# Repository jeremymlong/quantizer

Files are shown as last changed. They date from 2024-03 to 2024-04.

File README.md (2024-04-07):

# Dual Quantizer
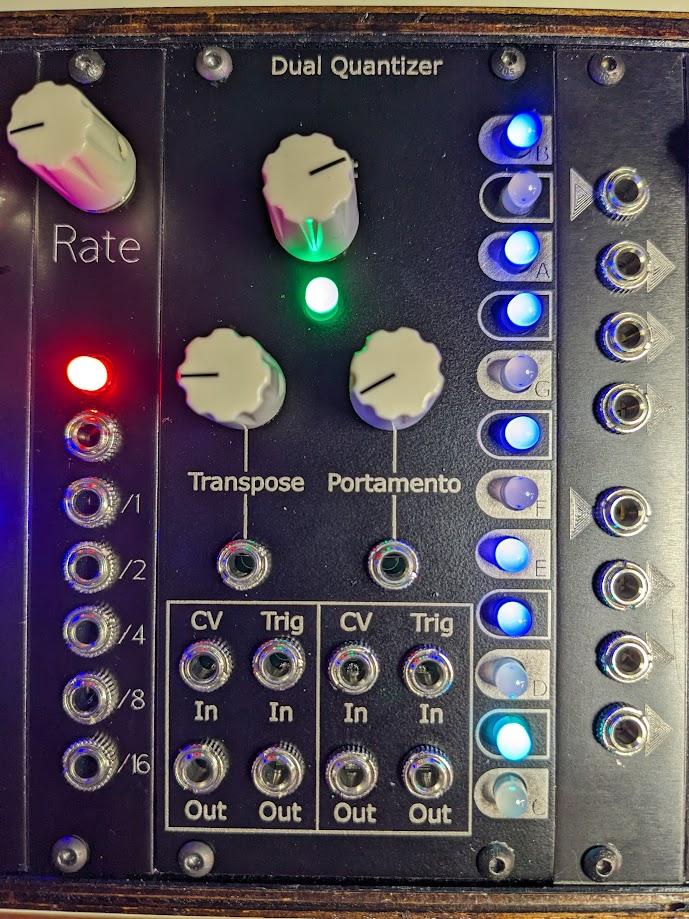
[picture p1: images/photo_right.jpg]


## Specs
 * Range 0 to 5V
 * Arduino Nano based
 * Encoder knob for selecting scale
 * Encoder button for selecting which quantizer is displayed on the LEDs
 * Transpose with CV control
 * Portamento with CV control
 * LED for displaying
    * Red for left quantizer, Green for right quantizer
    * Trigger in
    * Current scale
    * Current CV note out
 * Two quantizers
    * CV input
    * CV output
    * Trigger in - CV input is sampled on rising edge and output until next trigger.
    * Trigger out - A pulse out each time the CV output changes
 * Scales
    * Major
    * Minor natural
    * Minor harmonic
    * Pentatonic major
    * Pentatonic minor
    * Blues major
    * Blues minor
    * Chromatic

## Calibration
Use a multimeter to calibrate the voltage reference to 5.0V. This voltage reference is used by the Arduino and the MCP4921s. The easiest place to measure this is at the AREF socket. This can be done when doing other voltage tests when first applying power to the board.
1. Apply power to the board
1. Connect a multimeter to monitor AREF
1. Adjust the trim pot until the voltage reads 5.0V.

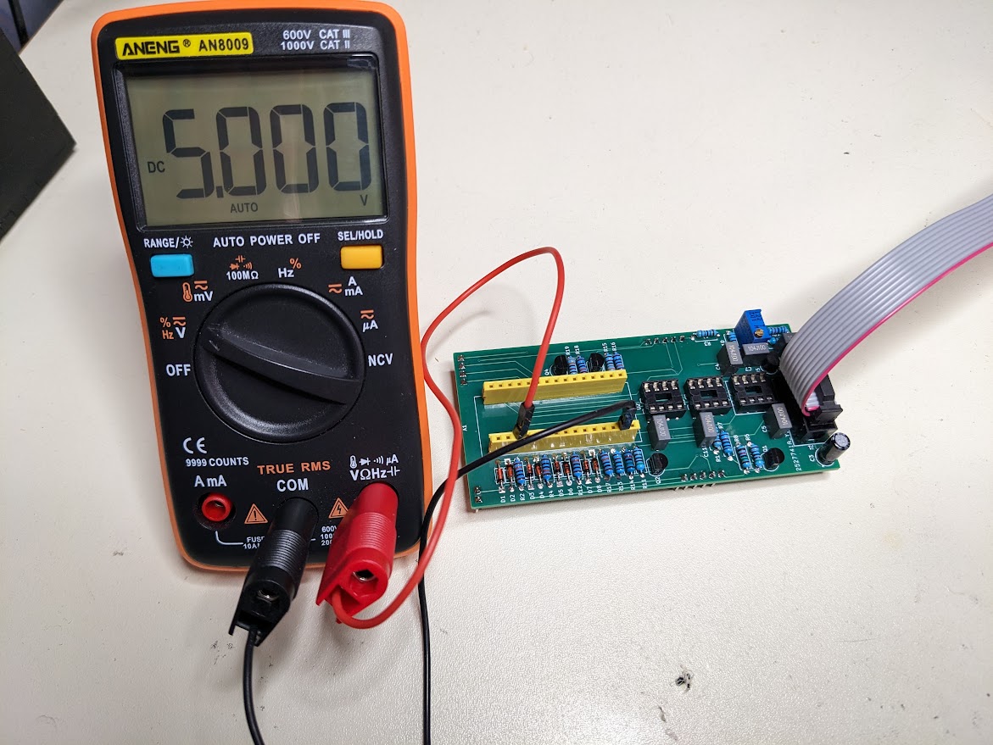
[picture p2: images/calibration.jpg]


## BOM
| Part | Quantity | Link |
|-----|-----|-----|
| Arduino Nano | 1 | [Tayda](https://www.taydaelectronics.com/nano-3-0-controller-compatible-with-arduino-nano-usb-driver.html) |
| MCP4921 DIP-8 | 2 | [Mouser](https://www.mouser.com/ProductDetail/Microchip-Technology/MCP4921-E-P?qs=1zyQUV6YKYz%252BhdPnOOm6sg%3D%3D), [Digikey](https://www.digikey.com/en/products/detail/microchip-technology/MCP4921-E-P/716280) |
| TL072 DIP-8 | 1 | [Tayda](https://www.taydaelectronics.com/tl072-low-noise-j-fet-dual-op-amp-ic.html) |
| TL431 TO-92 | 1 | [Tayda](https://www.taydaelectronics.com/tl431acl-tl431-precision-shunt-regulator.html) |
| 2N3904 TO-92 | 4 | [Tayda](https://www.taydaelectronics.com/2n3904-npn-general-propose-transistor.html) |
| 5mm WS2811 F5 LED | 13 | [AliExpress](https://www.aliexpress.us/item/2251832527100547.html?gatewayAdapt=glo2usa4itemAdapt), [ebay](https://www.ebay.com/itm/225210423475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)|
| 1x2 vertical pin header | 1 | [Tayda](https://www.taydaelectronics.com/40-pin-male-2-54-mm-single-row-pin-header-break-away-round-pin-gold-plated.html) |
| 1x4 vertical pin header | 1 | [Tayda](https://www.taydaelectronics.com/40-pin-male-2-54-mm-single-row-pin-header-break-away-round-pin-gold-plated.html) |
| 1x5 vertical pin header | 2 | [Tayda](https://www.taydaelectronics.com/40-pin-male-2-54-mm-single-row-pin-header-break-away-round-pin-gold-plated.html) |
| 1x2 vertical pin socket | 1 | [Tayda](https://www.taydaelectronics.com/2-pin-2-54-mm-single-row-female-pin-header.html) |
| 1x4 vertical pin socket | 1 | [Tayda](https://www.taydaelectronics.com/4-pin-2-54-mm-single-row-female-pin-header.html) |
| 1x5 vertical pin socket | 2 | [Tayda](https://www.taydaelectronics.com/5-pin-2-54-mm-single-row-female-pin-header.html) |
| Rotary encoder (footprint is Alps EC12E) | 1 | [Tayda](https://www.taydaelectronics.com/rotary-encoder-11mm-20-detents-d-shaft-with-switch-vertical.html) |
| 9mm vertical potentiometer 50k | 2 | [Tayda](https://www.taydaelectronics.com/50k-ohm-linear-taper-potentiometer-round-shaft-pcb-9mm.html) |
| Potentiometer 3296W 1k | 1 | [Tayda](https://www.taydaelectronics.com/1k-ohm-trimmer-potentiometer-cermet-25-turns-3296w.html) |
| 330 1/4W resisitor | 1 | [Tayda](https://www.taydaelectronics.com/330-ohm-1-4w-1-metal-film-resistor.html) |
| 1k 1/4W resisitor | 2 | [Tayda](https://www.taydaelectronics.com/10-x-resistor-1k-ohm-1-4w-1-metal-film-pkg-of-10.html) |
| 5.1k 1/4W resisitor | 2 | [Tayda](https://www.taydaelectronics.com/resistor-5-1k-ohm-1-4w-1-metal-film-pkg-of-10.html) |
| 10k 1/4W resisitor | 4 | [Tayda](https://www.taydaelectronics.com/10-x-resistor-10k-ohm-1-4w-1-metal-film-pkg-of-10.html) |
| 15k 1/4W resisitor | 2 | [Tayda](https://www.taydaelectronics.com/10-x-resistor-15k-ohm-1-4w-1-metal-film-pkg-of-10.html) |
| 33k 1/4W resisitor | 2 | [Tayda](https://www.taydaelectronics.com/resistor-33k-ohm-1-4w-1-metal-film-pkg-of-10.html) |
| 100k 1/4W resisitor | 6 | [Tayda](https://www.taydaelectronics.com/10-x-resistor-100k-ohm-1-4w-1-metal-film-pkg-of-10.html) |
| 10nF capacitor 5mm spacing | 2 | [Tayda](https://www.taydaelectronics.com/10nf-0-01uf-100v-5-polyester-film-box-type-capacitor.html) |
| 100nF capacitor 5mm spacing | 7 | [Tayda](https://www.taydaelectronics.com/0-1uf-100v-5-polyester-film-box-type-capacitor.html) |
| 10uF capacitor 5mm diameter, 2mm spacing | 2 | [Tayda](https://www.taydaelectronics.com/10uf-50v-105c-jrb-radial-electrolytic-capacitor-5x11mm.html) |
| PJ301M or PJ-3001F (Thonkiconn) | 10 | [Tayda](https://www.taydaelectronics.com/pj-3001f-3-5-mm-mono-phone-jack.html) |
| 2x5 IDC Shrouded header (no reverse power protection on this) | 1 | [Tayda](https://www.taydaelectronics.com/10-pin-box-header-connector-2-54mm.html) |
| Schottky diode DO-35 (signal diodes work too) | 8 | [Tayda](https://www.taydaelectronics.com/1n5819-schottky-barrier-diode-1a-40v.html) |
| Knobs | 3 | [Tayda](https://www.taydaelectronics.com/knob-davies-1900h-clone-cream.html) |

## TODO
 * Editable scale
 * Chord mode

## Arduino Dependencies
 * [Adafruit_NeoPixel](https://github.com/adafruit/Adafruit_NeoPixel)
 * [AUnit](https://github.com/bxparks/AUnit) (for tests)

## Notes about LEDs
The 12 scale LED are not included on the schematic or board. My hope was to use these boards for another project. I directly mounted the LEDs to the panel with hot glue and wired them point to point. Wires are connected to the leads of the first LED. On the back of the board I left the leads long and connected the power wires as pictured below. The second LED is at the bottom of the panel and the rest wire up the panel to the top.

### Reversing LED order
You can reverse the LED order if you want the lowest note at the top of the panel. There's a define commented out at the top of leds.cpp `REVERSE_LED_ORDER`. Just uncomment that line to reverse the order.

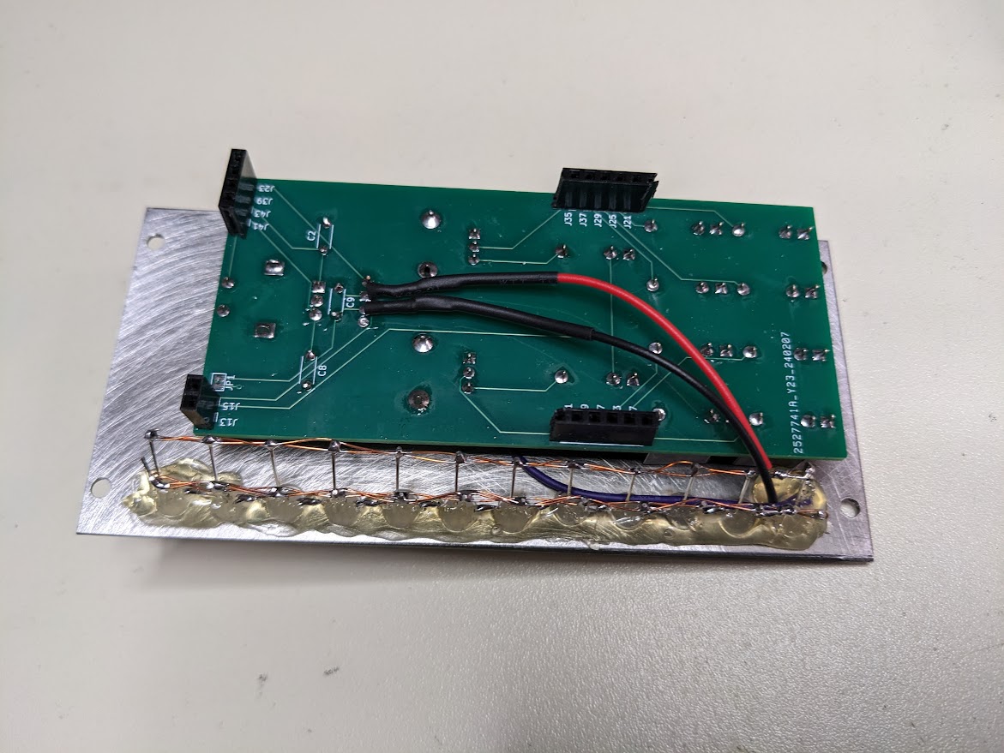
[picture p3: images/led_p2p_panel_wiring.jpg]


LEDs are WS2811 (NeoPixel) style, but in a traditional 5mm form factor.
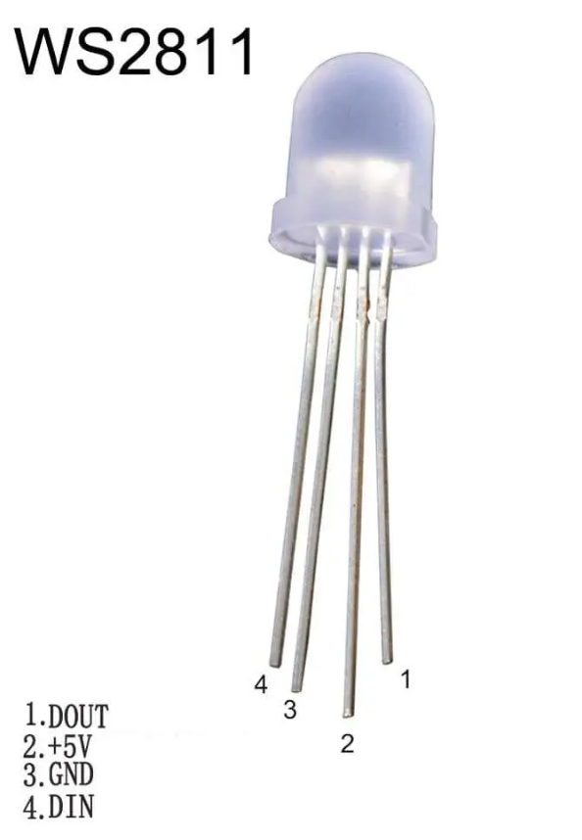
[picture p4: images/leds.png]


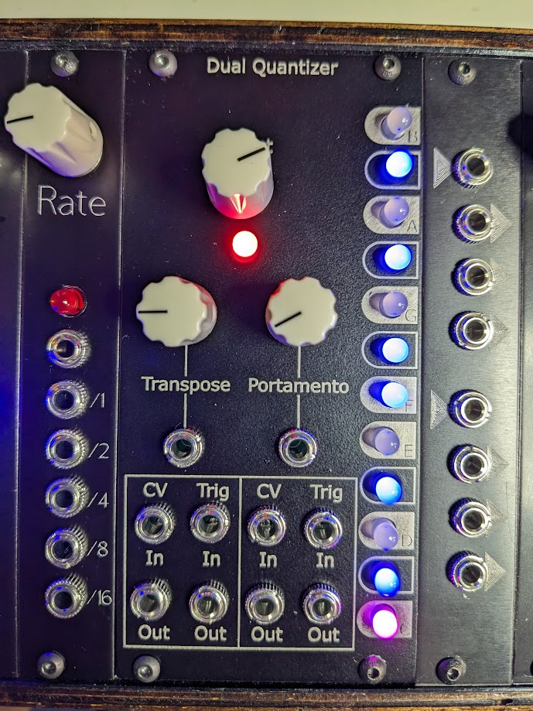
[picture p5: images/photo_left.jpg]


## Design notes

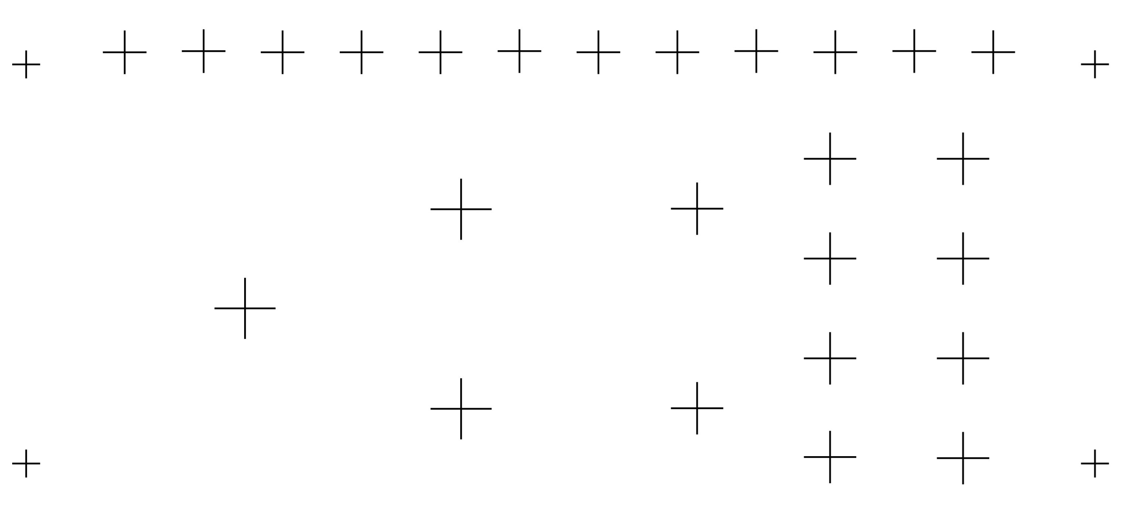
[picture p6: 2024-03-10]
hardware/panel/drill.png

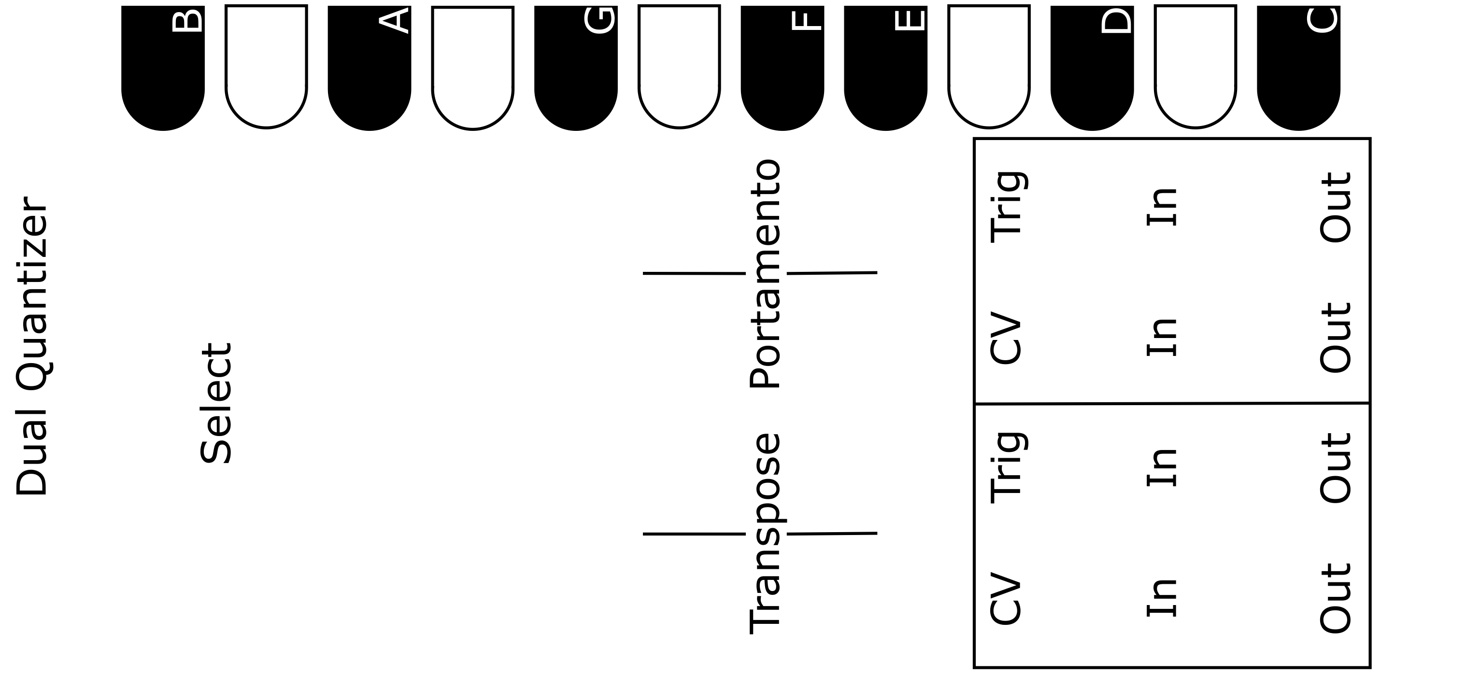
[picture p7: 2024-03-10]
hardware/panel/graphics.png

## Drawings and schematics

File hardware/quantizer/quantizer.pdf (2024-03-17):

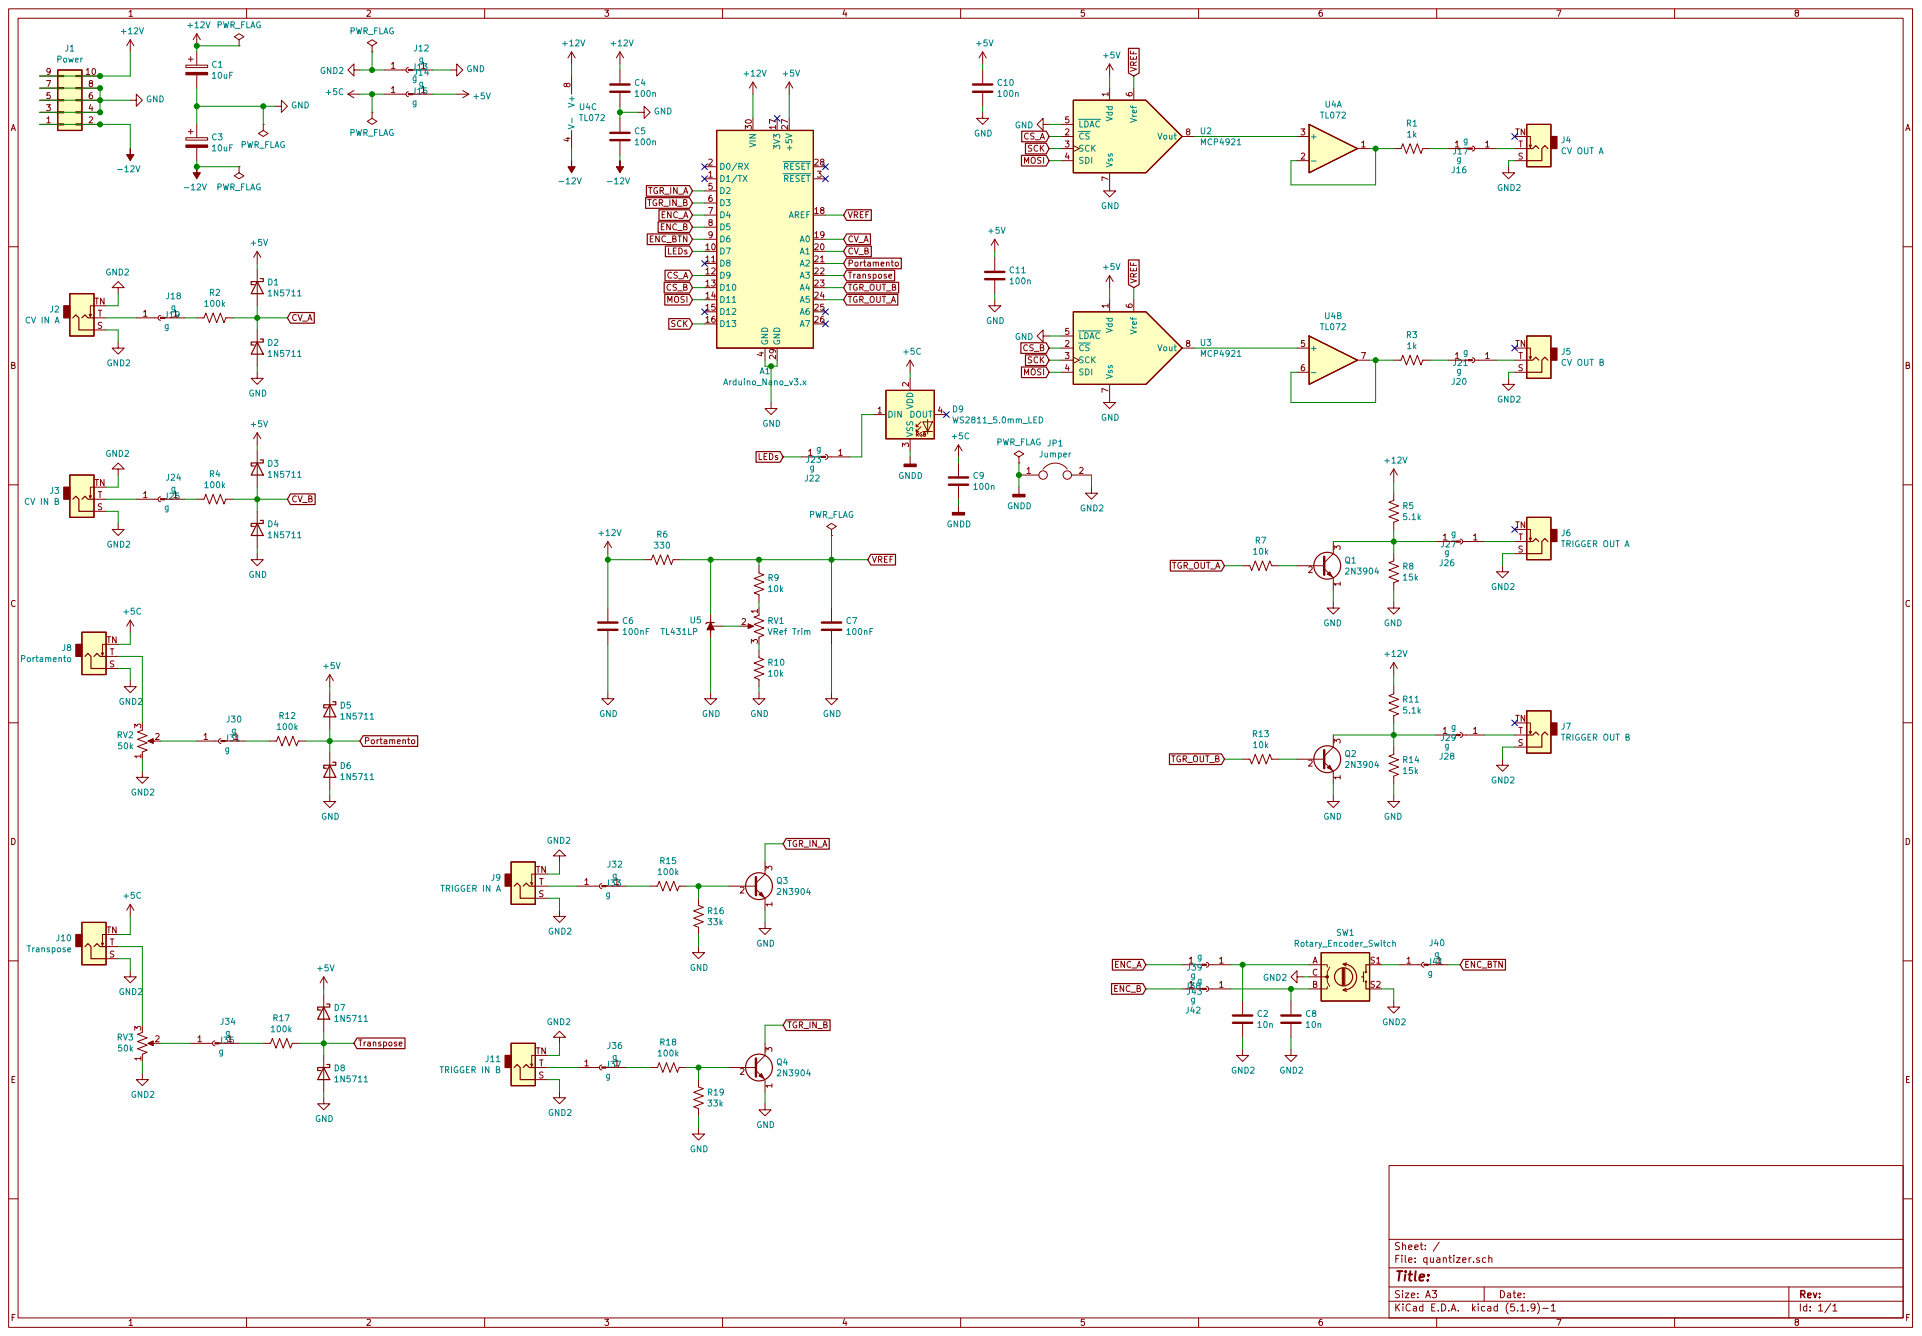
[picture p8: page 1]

File: quantizer.sch Sheet: /

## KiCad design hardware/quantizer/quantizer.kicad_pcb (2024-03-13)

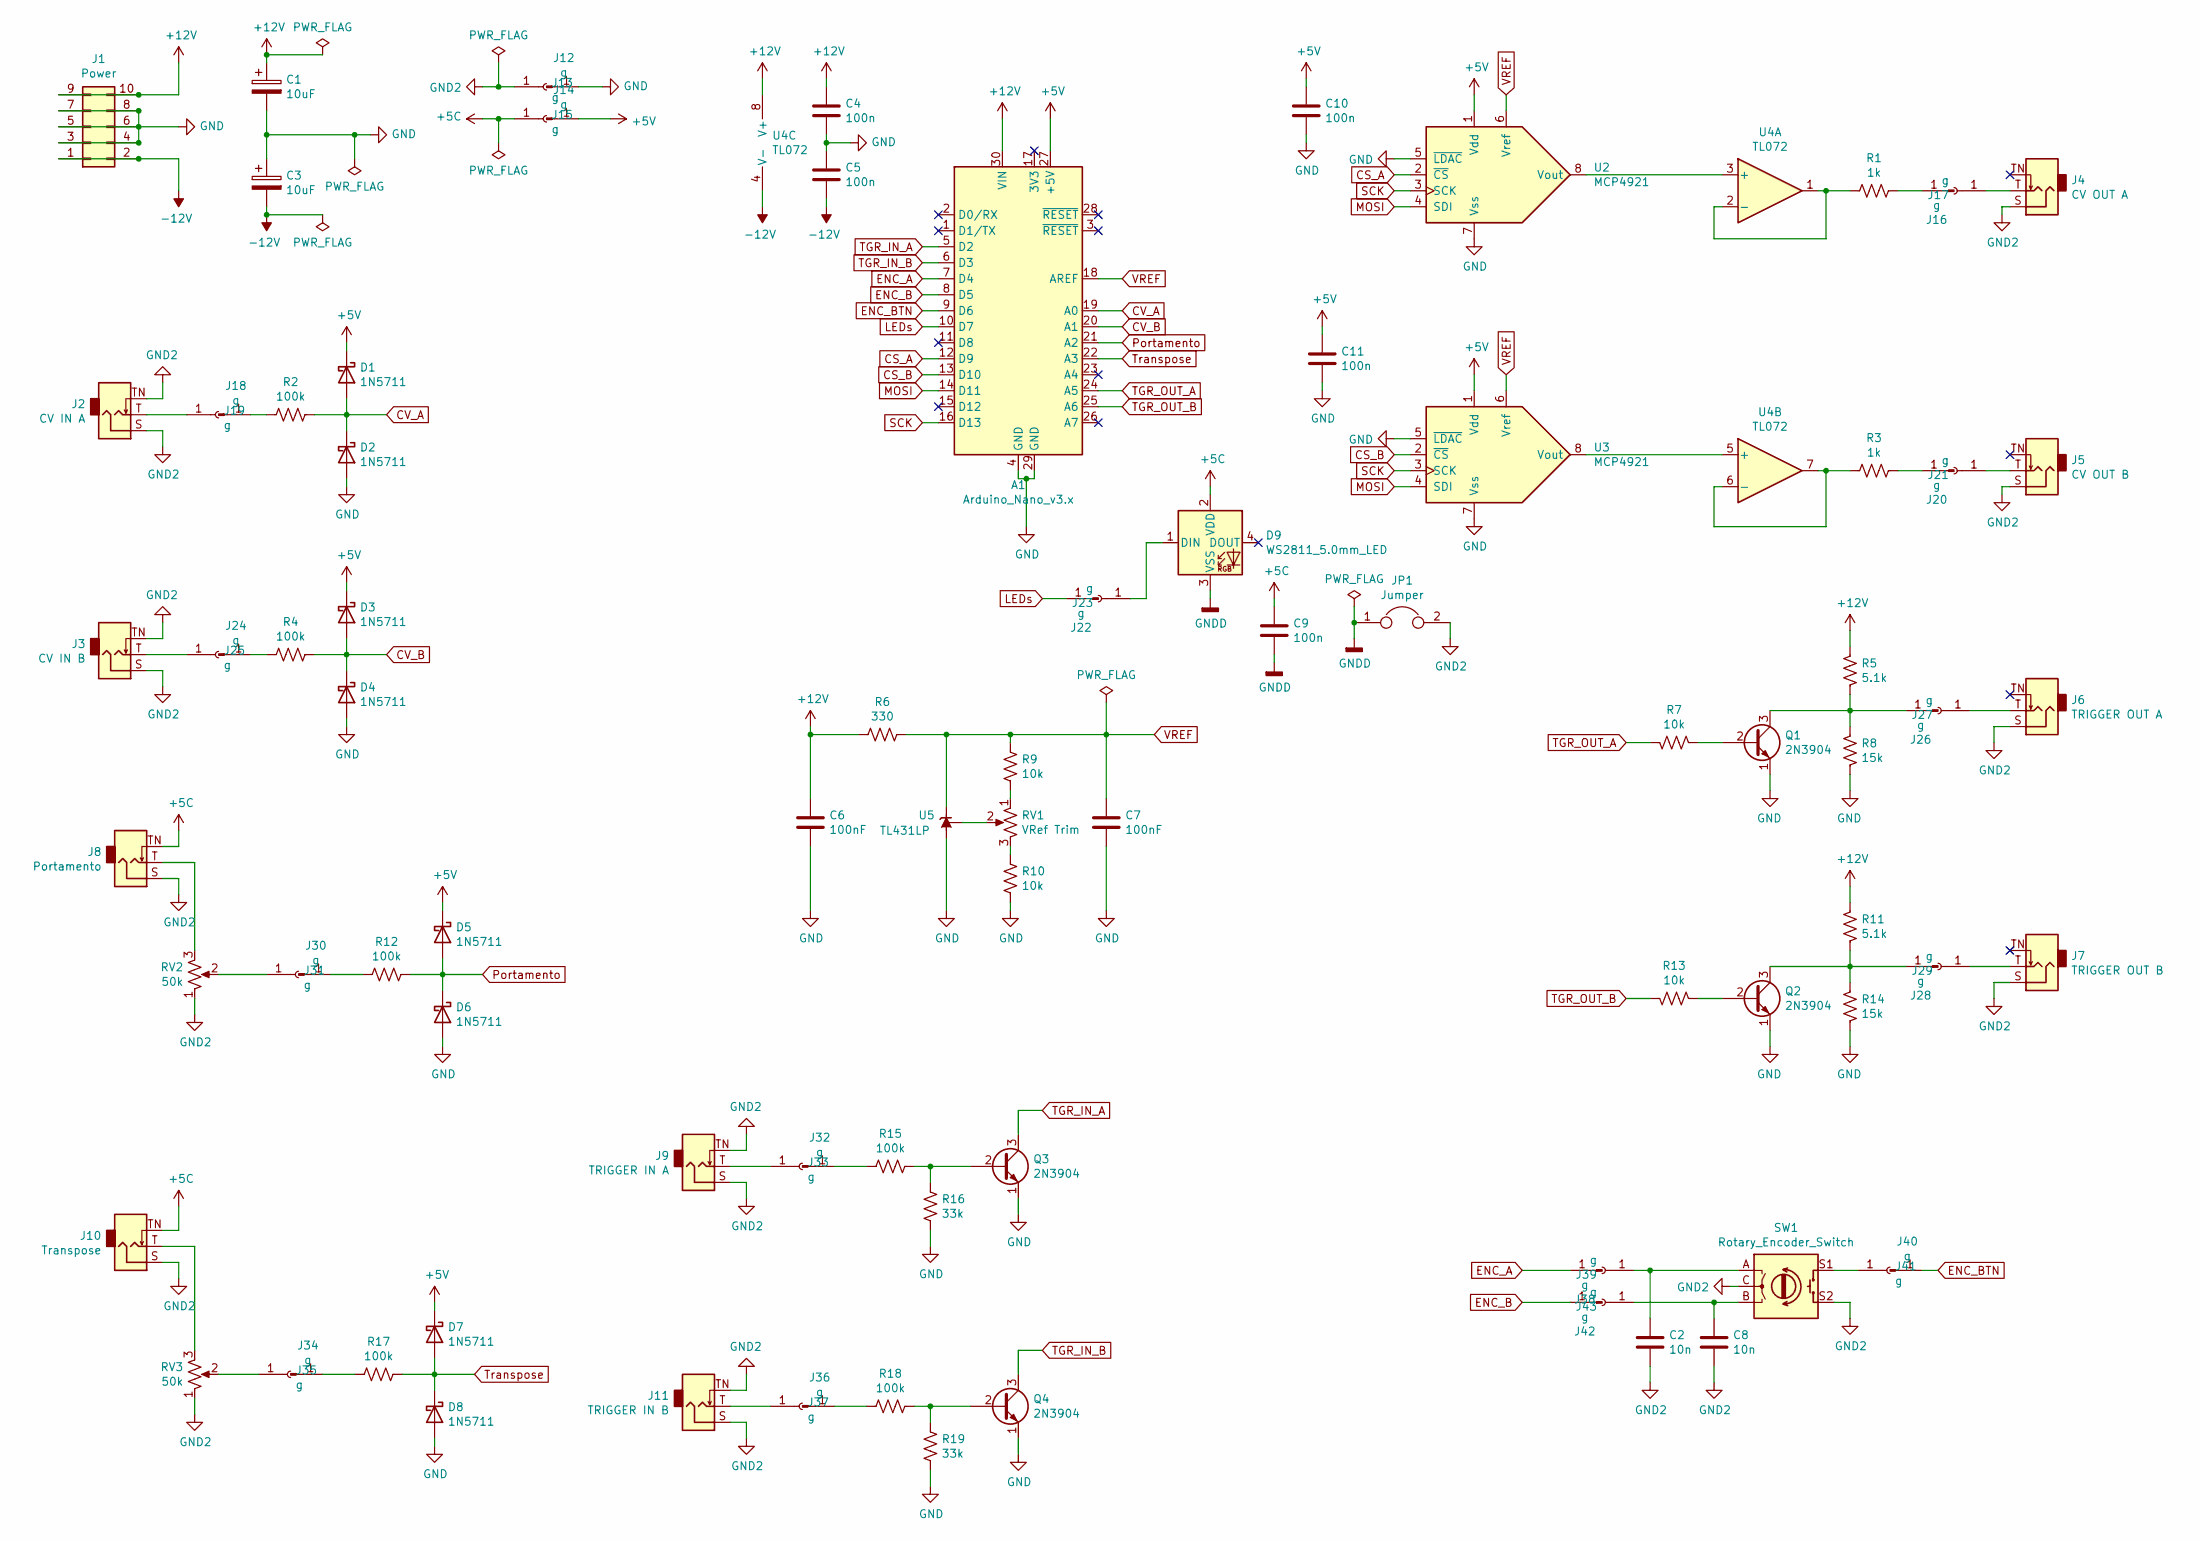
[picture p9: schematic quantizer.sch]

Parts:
A1: Arduino_Nano_v3.x; Arduino_Nano
C1, C3: 10uF; CP_Radial_D5.0mm_P2.00mm
C2, C8: 10n; C_Disc_D4.3mm_W1.9mm_P5.00mm
C4, C5, C9, C10, C11: 100n; C_Disc_D4.3mm_W1.9mm_P5.00mm
C6, C7: 100nF; C_Disc_D4.3mm_W1.9mm_P5.00mm
D1, D2, D3, D4, D5, D6, D7, D8: 1N5711; D_DO-35_SOD27_P7.62mm_Horizontal
D9: WS2811_5.0mm_LED; LED_D5.0mm-WS2811
J1: Power; IDC-Header_2x05_P2.54mm_Vertical
J2: CV IN A; Jack_3.5mm_QingPu_WQP-PJ398SM_Vertical_CircularHoles
J3: CV IN B; Jack_3.5mm_QingPu_WQP-PJ398SM_Vertical_CircularHoles
J4: CV OUT A; Jack_3.5mm_QingPu_WQP-PJ398SM_Vertical_CircularHoles
J5: CV OUT B; Jack_3.5mm_QingPu_WQP-PJ398SM_Vertical_CircularHoles
J6: TRIGGER OUT A; Jack_3.5mm_QingPu_WQP-PJ398SM_Vertical_CircularHoles
J7: TRIGGER OUT B; Jack_3.5mm_QingPu_WQP-PJ398SM_Vertical_CircularHoles
J8: Portamento; Jack_3.5mm_QingPu_WQP-PJ398SM_Vertical_CircularHoles
J9: TRIGGER IN A; Jack_3.5mm_QingPu_WQP-PJ398SM_Vertical_CircularHoles
J10: Transpose; Jack_3.5mm_QingPu_WQP-PJ398SM_Vertical_CircularHoles
J11: TRIGGER IN B; Jack_3.5mm_QingPu_WQP-PJ398SM_Vertical_CircularHoles
J12, J13, J14, J15, J16, J17, J18, J19, J20, J21, J22, J23, J24, J25, J26, J27, J28, J29, J30, J31, J32, J33, J34, J35, J36, J37, J38, J39, J40, J41, J42, J43: g; PinHeader_1x01_P2.54mm_Vertical
JP1: Jumper; SolderJumper-2_P1.3mm_Bridged2Bar_Pad1.0x1.5mm
Q1, Q2, Q3, Q4: 2N3904; TO-92_Inline
R1, R3: 1k; R_Axial_DIN0207_L6.3mm_D2.5mm_P7.62mm_Horizontal
R2, R4, R12, R15, R17, R18: 100k; R_Axial_DIN0207_L6.3mm_D2.5mm_P7.62mm_Horizontal
R5, R11: 5.1k; R_Axial_DIN0207_L6.3mm_D2.5mm_P7.62mm_Horizontal
R6: 330; R_Axial_DIN0207_L6.3mm_D2.5mm_P7.62mm_Horizontal
R7, R9, R10, R13: 10k; R_Axial_DIN0207_L6.3mm_D2.5mm_P7.62mm_Horizontal
R8, R14: 15k; R_Axial_DIN0207_L6.3mm_D2.5mm_P7.62mm_Horizontal
R16, R19: 33k; R_Axial_DIN0207_L6.3mm_D2.5mm_P7.62mm_Horizontal
RV1: VRef Trim; Potentiometer_Bourns_3296W_Vertical
RV2, RV3: 50k; Potentiometer_Alpha_RD901F-40-00D_Single_Vertical_CircularH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
SW1: Rotary_Encoder_Switch; RotaryEncoder_Alps_EC12E-Switch_Vertical_H20mm
U2, U3: MCP4921; DIP-8_W7.62mm_LongPads
U4: TL072; DIP-8_W7.62mm_Socket_LongPads
U5: TL431LP; TO-92_Inline

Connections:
+5C: C9.1, D9.2 (VDD), J8.TN, J10.TN, J15.1
+5V: A1.27 (+5V), C10.1, C11.1, D1.1 (K), D3.1 (K), D5.1 (K), D7.1 (K), J14.1, U2.1 (Vdd), U3.1 (Vdd)
+12V: A1.30 (VIN), C1.1, C4.1, C6.1, J1.9, J1.10, R5.1, R6.1, R11.1, U4.8 (V+)
-12V: C3.2, C5.2, J1.1, J1.2, U4.4 (V-)
CS_A: A1.12 (D9), U2.2 (~CS)
CS_B: A1.13 (D10), U3.2 (~CS)
CV_A: A1.19 (A0), D1.2 (A), D2.1 (K), R2.2
CV_B: A1.20 (A1), D3.2 (A), D4.1 (K), R4.2
ENC_A: A1.7 (D4), J38.1
ENC_B: A1.8 (D5), J42.1
ENC_BTN: A1.9 (D6), J40.1
GND: A1.4 (GND), A1.29 (GND), C1.2, C3.1, C4.2, C5.1, C6.2, C7.2, C10.2, C11.2, D2.2 (A), D4.2 (A), D6.2 (A), D8.2 (A), J1.3, J1.4, J1.5, J1.6, J1.7, J1.8, J12.1, Q1.1 (E), Q2.1 (E), Q3.1 (E), Q4.1 (E), R8.2, R10.1, R14.2, R16.2, R19.2, U2.5 (~LDAC), U2.7 (Vss), U3.5 (~LDAC), U3.7 (Vss), U5.2 (A)
GND2: C2.2, C8.2, J2.S, J2.TN, J3.S, J3.TN, J4.S, J5.S, J6.S, J7.S, J8.S, J9.S, J9.TN, J10.S, J11.S, J11.TN, J13.1, JP1.2, RV2.1, RV3.1, SW1.C, SW1.S2
GNDD: C9.2, D9.3 (VSS), JP1.1
LEDs: A1.10 (D7), J22.1
MOSI: A1.14 (D11), U2.4 (SDI), U3.4 (SDI)
unnamed: C2.1, J39.1, SW1.A
unnamed: C8.1, J43.1, SW1.B
unnamed: D9.1 (DIN), J23.1
unnamed: J8.T, RV2.3
unnamed: J10.T, RV3.3
unnamed: J11.T, J37.1
unnamed: J16.1, R1.2
unnamed: J4.T, J17.1
unnamed: J18.1, R2.1
unnamed: J2.T, J19.1
unnamed: J20.1, R3.2
unnamed: J5.T, J21.1
unnamed: J24.1, R4.1
unnamed: J3.T, J25.1
unnamed: J26.1, Q1.3 (C), R5.2, R8.1
unnamed: J6.T, J27.1
unnamed: J28.1, Q2.3 (C), R11.2, R14.1
unnamed: J7.T, J29.1
unnamed: J30.1, R12.1
unnamed: J31.1, RV2.2
unnamed: J32.1, R15.1
unnamed: J9.T, J33.1
unnamed: J34.1, R17.1
unnamed: J35.1, RV3.2
unnamed: J36.1, R18.1
unnamed: J41.1, SW1.S1
unnamed: Q1.2 (B), R7.1
unnamed: Q2.2 (B), R13.1
unnamed: Q3.2 (B), R15.2, R16.1
unnamed: Q4.2 (B), R18.2, R19.1
unnamed: R1.1, U4.1, U4.2 (-)
unnamed: R3.1, U4.6 (-), U4.7
unnamed: R9.1, RV1.1
unnamed: R10.2, RV1.3
unnamed: RV1.2, U5.1 (REF)
unnamed: U2.8 (Vout), U4.3 (+)
unnamed: U3.8 (Vout), U4.5 (+)
Portamento: A1.21 (A2), D5.2 (A), D6.1 (K), R12.2
SCK: A1.16 (D13), U2.3 (SCK), U3.3 (SCK)
TGR_IN_A: A1.5 (D2), Q3.3 (C)
TGR_IN_B: A1.6 (D3), Q4.3 (C)
TGR_OUT_A: A1.24 (A5), R7.2
Transpose: A1.22 (A3), D7.2 (A), D8.1 (K), R17.2
VREF: A1.18 (AREF), C7.1, R6.2, R9.2, U2.6 (Vref), U3.6 (Vref), U5.3 (K)

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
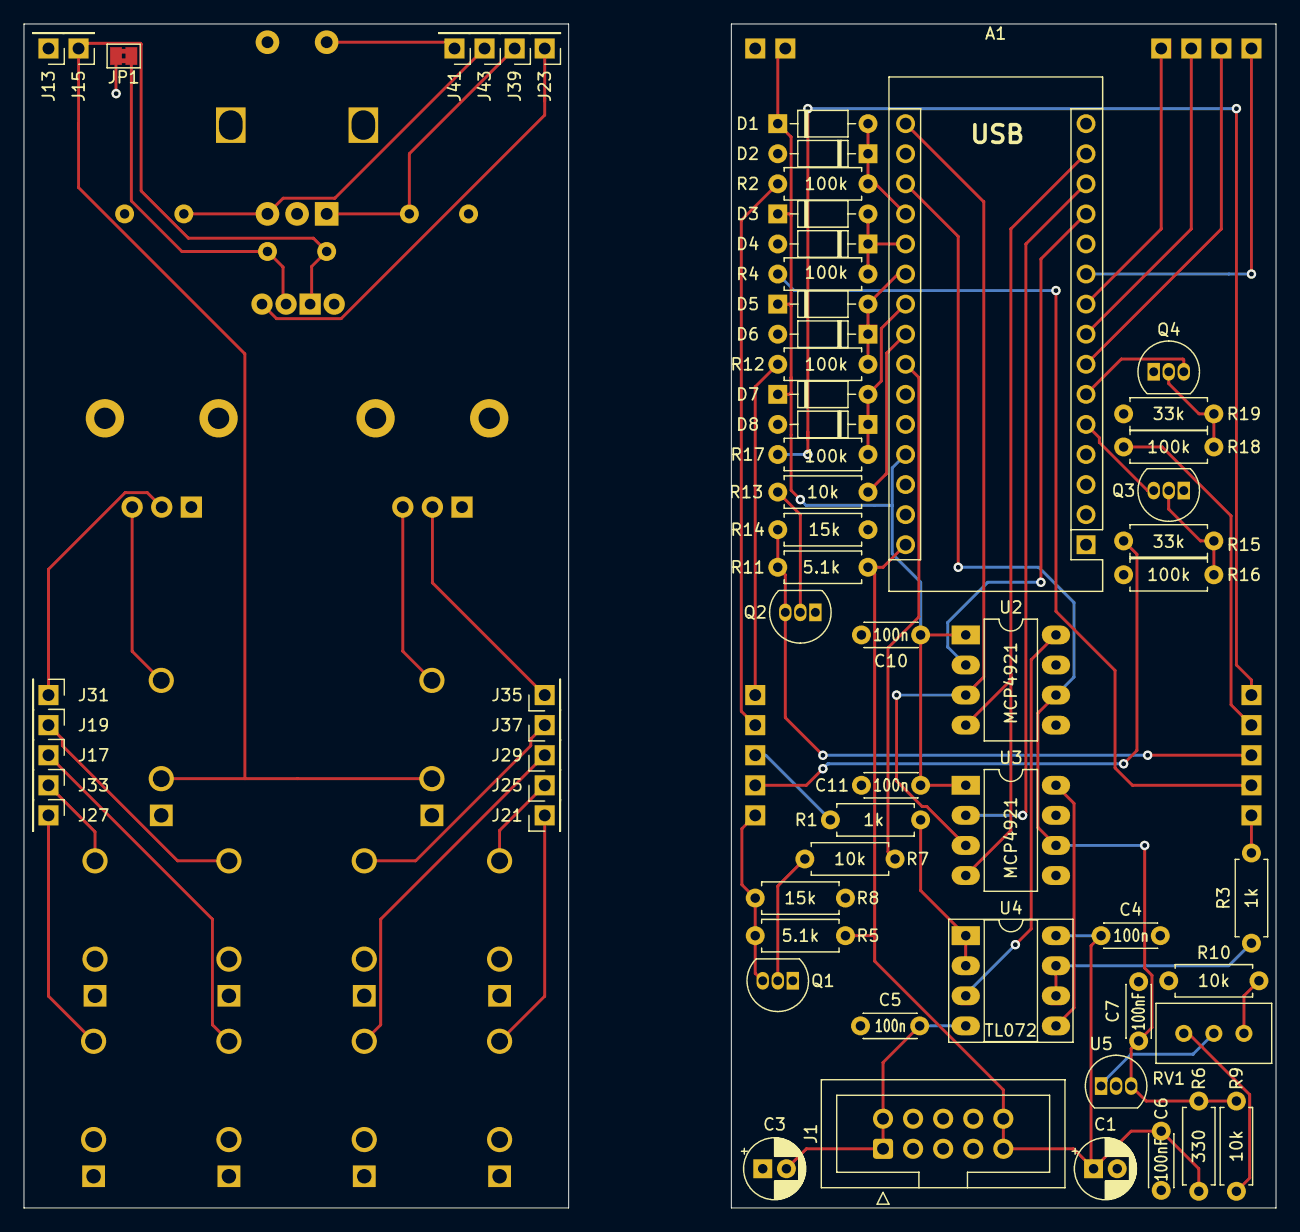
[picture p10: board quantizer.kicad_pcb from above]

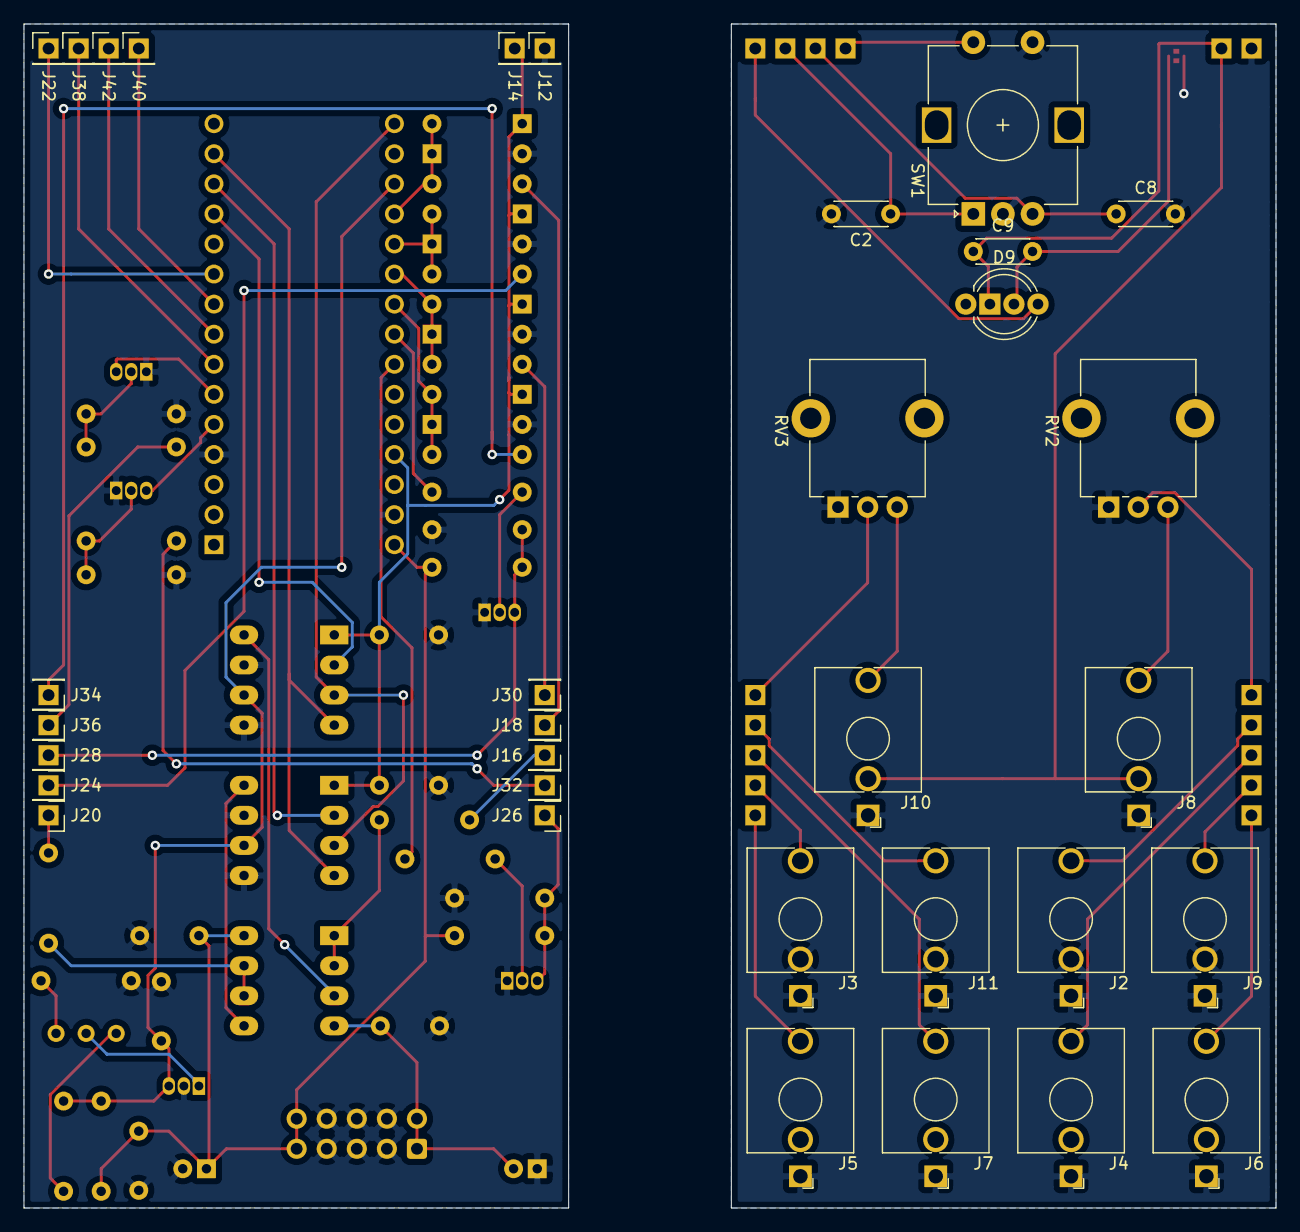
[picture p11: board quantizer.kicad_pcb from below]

Board: 2 copper layers, 105.7 x 100.0 mm, 96 parts (33 on the bottom side), 61 nets.

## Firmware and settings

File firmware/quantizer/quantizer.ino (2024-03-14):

#if 1

#include "rotary_encoder.h"
#include "button.h"
#include "cv_quantizer.h"
#include <SPI.h>

quantizer::rotary_encoder encoder(quantizer::pins::encoder_a, quantizer::pins::encoder_b);
quantizer::button encoder_button(quantizer::pins::encoder_button);
quantizer::cv_quantizer cv_quantizer;
quantizer::leds leds;
void setup() {
    SPI.begin();
    analogReference(EXTERNAL);
    
    encoder.increased = [] { cv_quantizer.next_scale(); };
    encoder.decreased = [] { cv_quantizer.previous_scale(); };
    encoder_button.on_button_pressed = [] { cv_quantizer.toggle_display_side(); };

    pinMode(quantizer::pins::trigger_in_a, INPUT_PULLUP);
    pinMode(quantizer::pins::trigger_in_b, INPUT_PULLUP);

    attachInterrupt(digitalPinToInterrupt(quantizer::pins::trigger_in_a), []{
        cv_quantizer.trigger_a(!digitalRead(quantizer::pins::trigger_in_a));
    }, CHANGE);

    attachInterrupt(digitalPinToInterrupt(quantizer::pins::trigger_in_b), []{
        cv_quantizer.trigger_b(!digitalRead(quantizer::pins::trigger_in_b));
    }, CHANGE);

    cv_quantizer.begin();
}

void loop() {
    cv_quantizer.loop();
    encoder.loop();
    encoder_button.loop();
}

#else

#include "test/cv_quantizer_tests.h"
#include "test/leds_tests.h"
#include <AUnit.h>

void setup() {
    Serial.begin(115200);
}

void loop() {
    aunit::TestRunner::run();
}

#endif

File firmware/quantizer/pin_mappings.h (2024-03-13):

#pragma once
#include <Arduino.h>
namespace quantizer {
namespace pins {
    const int trigger_in_a = 2;
    const int trigger_in_b = 3;
    const int encoder_a = 4;
    const int encoder_b = 5;
    const int encoder_button = 6;
    const int leds = 7;
    // 8
    const int dac_a_select = 9;
    const int dac_b_select = 10;
    // MOSI is 11
    // MISO is 12
    // SCK is 13
    const int cv_input_a = A0;
    const int cv_input_b = A1;
    const int portamento = A2;
    const int base_note = A3;
    const int trigger_out_b = A4;
    const int trigger_out_a = A5;
    // A6
    // A7
}
}

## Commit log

2024-03-12 Fixed trigger in issue
    [channel.cpp]
2024-03-13 Updated brd/sch pin change, added photos
    [quantizer.kicad_pcb]
2024-03-15 Updated README: BOM, calibration and LEDs
    [quantizer.sch]
2024-03-15 More LED description
2024-03-17 Added links to BOM
2024-03-17 Added quantizer-cache.lib and PDF of schematic
2024-04-07 Added reverse LED order option
2024-04-07 Clarification about LED order
